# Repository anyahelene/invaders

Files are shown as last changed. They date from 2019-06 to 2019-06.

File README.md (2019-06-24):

# invaders
##### A hand-held retro console based on the ATmega328P chip
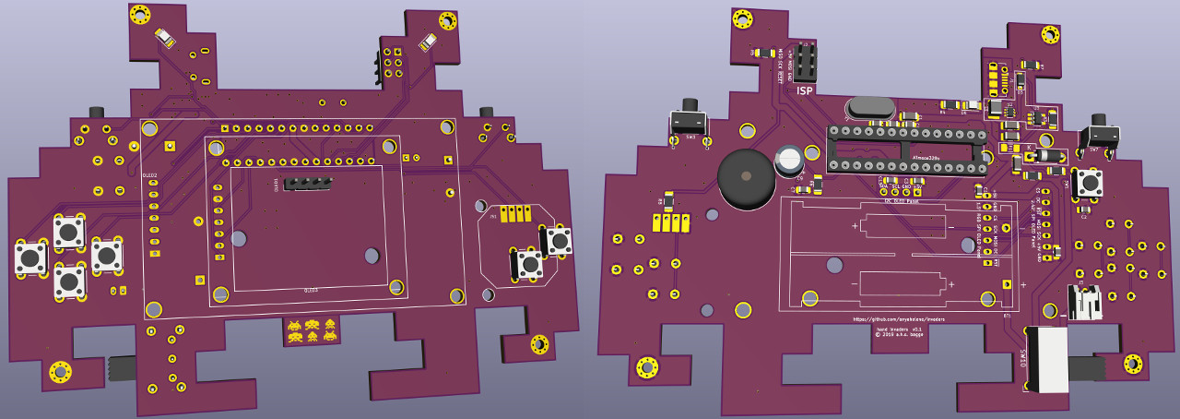
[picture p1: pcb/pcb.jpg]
3D model


## Features
* [ATmega328P](https://www.microchip.com/wwwproducts/en/ATMEGA328P) as the CPU, with
   * 16 MHz clock
   * 32 KiB flash memory for programs
   * 2 KiB static ram
   * 1 KiB EEPROM
* Choice of one of three OLED displays:
   * 2.42" monochrome 128x64 OLED with SPI interface, e.g., [this one from DIYMORE](https://www.diymore.cc/collections/display-module/products/2-42-inch-12864-oled-display-module-iic-i2c-spi-serial-for-arduino-c51-stm32-green-white-blue-yellow)
   * 1.5" color 128x128 OLED with SPI interface, e.g., [this one from Waveshare](https://www.waveshare.com/1.5inch-RGB-OLED-Module.htm)
   * 1.3" monochrome 128x64 OLED with I2C interface, found as infinite clones such as [this one from Luxorparts](https://www.kjell.com/no/produkter/elektro-og-verktoy/elektronikk/optokomponenter/led-lcd-skjermer/luxorparts-grafisk-oled-skjerm-128-x-64-piksler-1-3--p87946)
   * The board has pin headers and mounting holes for these three displays, but other display sizes might fit, and different pinouts might be accommodated by wires
   * The above displays are available from Ebay ($2.50 for a small display, up to ~$18 for large/color), and similar displays can be found at [Adafruit](https://adafruit.com/), [Sparkfun](https://sparkfun.com/) or your local electronics store
* Four directional buttons on the left-hand side
* [Thumbstick (PSP1000 replacement)](https://www.adafruit.com/product/444) *or* two buttons on the right-hand side
* Two trigger buttons on the top edge
* Reset button on the bottom side
* Space for 2xAAA batteries + also a JST-PH battery connector (as seen on the micro:bit)
* Micro USB power connector
* 6 pin AVR ICSP header for programming
* Space for a tiny speaker/buzzer
* Power led + two controllable leds
* Four M2 mounting holes

## (Soft|Firm)ware
* TBD

## Circuit board
* [KiCad](http://www.kicad-pcb.org/) files for the board can be found in the [pcb/](pcb/) subdirectory.
* You also need the symbols and footprints from https://github.com/anyahelene/a-symbols
* Alternatively, the board can be manufactured directly from the Gerber files in [pcb/fab/](pcb/fab/).
* An [interactive BOM](https://htmlpreview.github.io/?https://github.com/anyahelene/invaders/blob/master/pcb/bom/ibom.html) is available in [pcb/bom/](pcb/bom/)

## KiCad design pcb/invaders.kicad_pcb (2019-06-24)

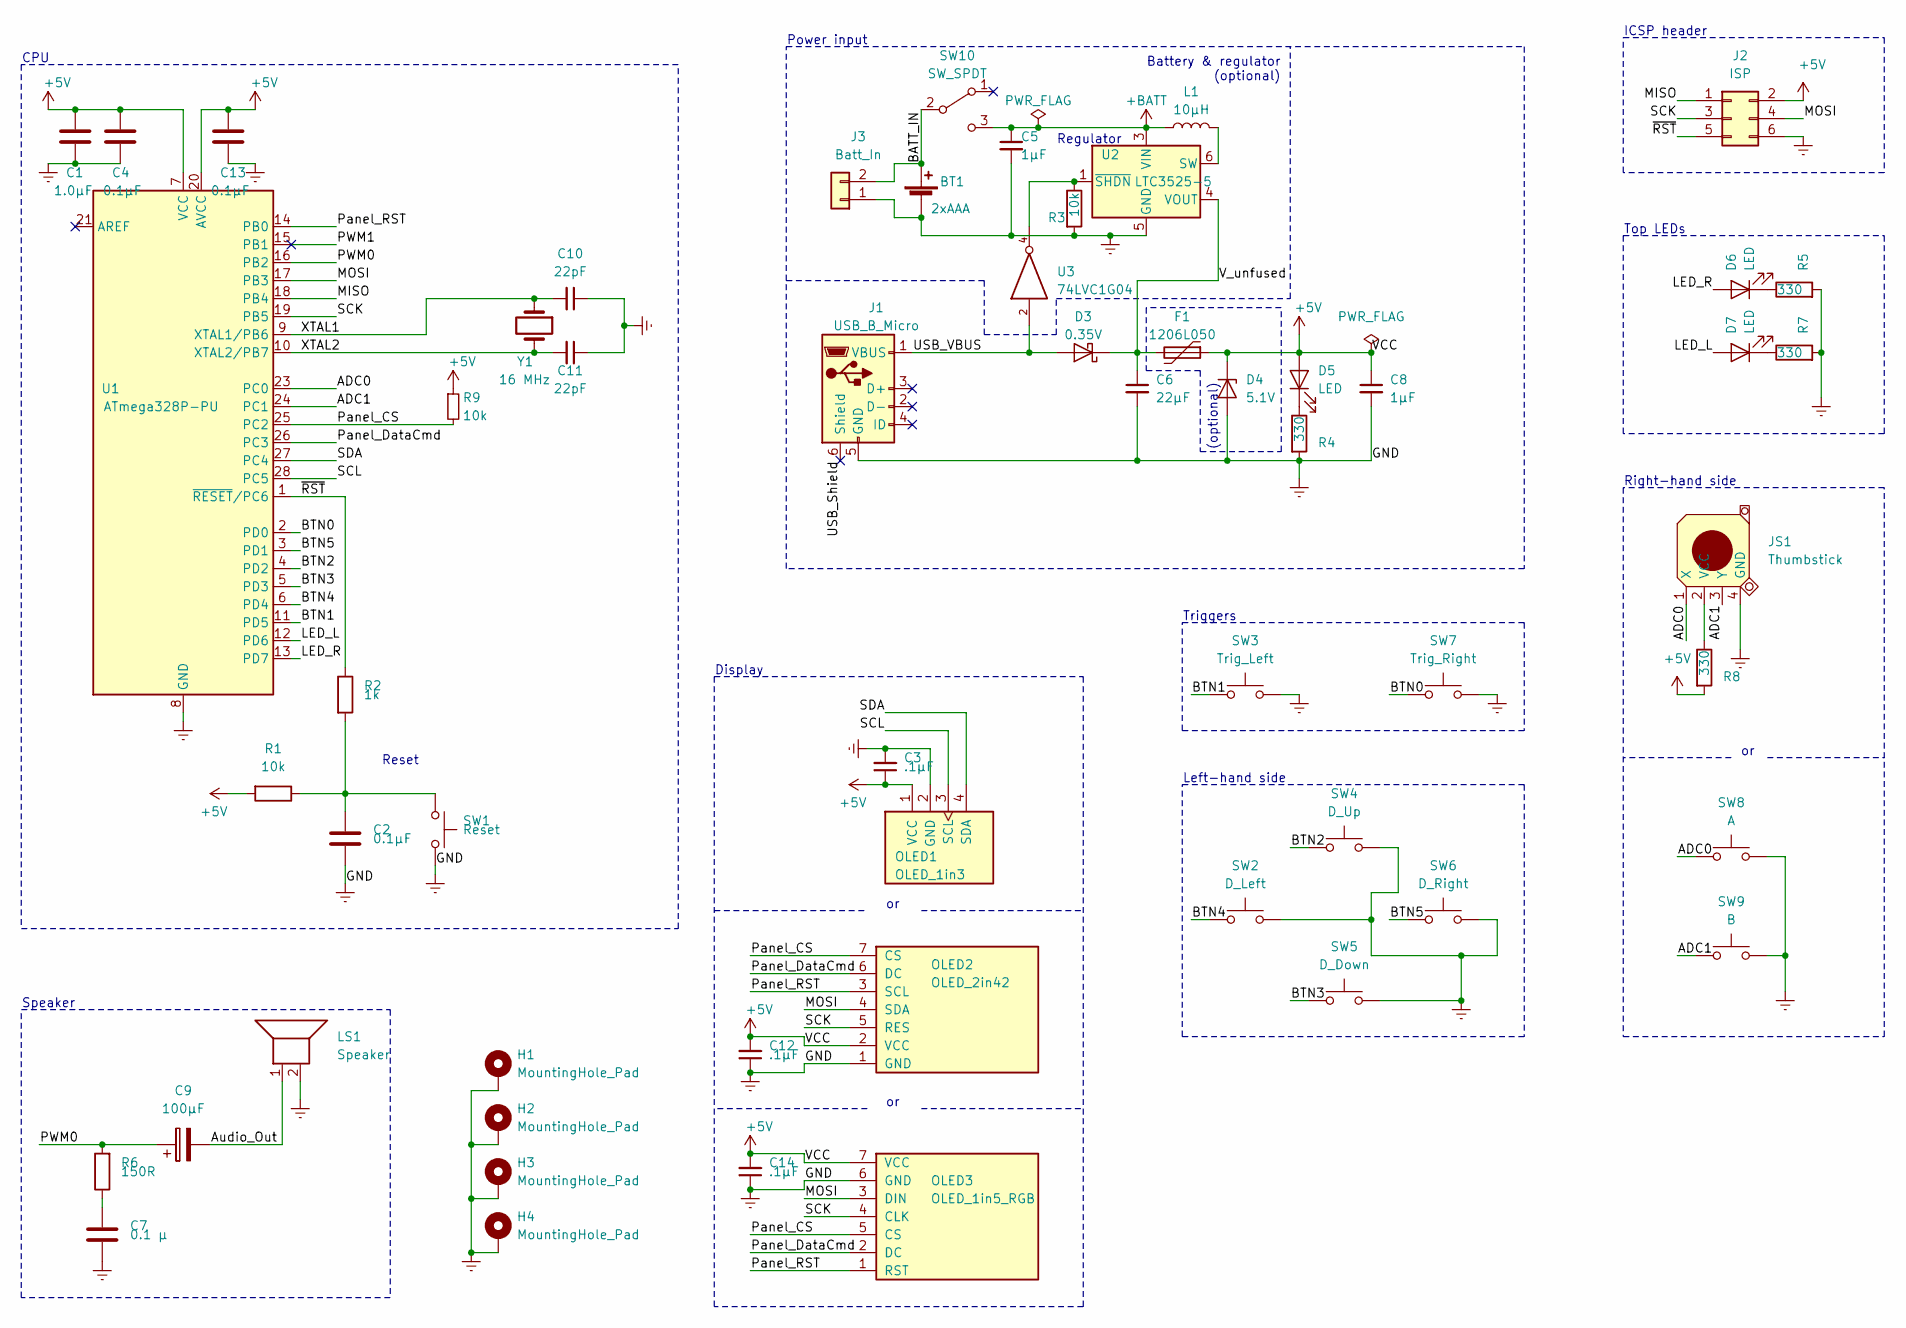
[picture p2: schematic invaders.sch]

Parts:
BT1: 2xAAA; BatteryHolder_Keystone_2468_2xAAA; Part Keystone 2468
C1: 1.0µF; C_1206_3216Metric_Pad1.42x1.75mm_HandSolder
C2, C4, C13: 0.1µF; C_0805_2012Metric_Pad1.15x1.40mm_HandSolder
C3, C12, C14: .1µF; C_0805_2012Metric_Pad1.15x1.40mm_HandSolder
C5, C8: 1µF; C_1206_3216Metric_Pad1.42x1.75mm_HandSolder
C6: 22µF; C_1206_3216Metric_Pad1.42x1.75mm_HandSolder; Part Taiyo LMK316ABJ226ML-T
C7: 0.1 µ; C_0805_2012Metric_Pad1.15x1.40mm_HandSolder
C9: 100µF; CP_Radial_D6.3mm_P2.50mm
C10, C11: 22pF; C_0805_2012Metric_Pad1.15x1.40mm_HandSolder
D3: 0.35V; D_SOD-123F; Part Rohm RSX101MM-30TR
D4: 5.1V; D_DO-41_SOD81_P7.62mm_Horizontal; Part RND 1N4733A
D5, D6, D7: LED; LED_1206_3216Metric_Pad1.42x1.75mm_HandSolder
F1: 1206L050; Fuse_1206_3216Metric_Pad1.42x1.75mm_HandSolder
H1, H2, H3, H4: MountingHole_Pad; MountingHole_2.2mm_M2_Pad_Via
J1: USB_B_Micro; USB_Micro-B_Molex-105017-0001; Part Molex 105017
J2: ISP; PinHeader_2x03_P2.54mm_Vertical
J3: Batt_In; JST_PH_S2B-PH-K_1x02_P2.00mm_Horizontal
JS1: Thumbstick; psp_thumbstick; Part PSP1000 thumbstick
L1: 10µH; L_1210_3225Metric_Pad1.42x2.65mm_HandSolder; Part Murata DFE322512C 1277A
LS1: Speaker; Buzzer_12x9.5RM7.6
OLED1: OLED_1in3; OLED_1in3_i2c
OLED2: OLED_2in42; OLED_2in42_spi_i2c
OLED3: OLED_1in5_RGB; OLED_1in5_spi_rgb
R1, R3, R9: 10k; R_1206_3216Metric_Pad1.42x1.75mm_HandSolder
R2: 1k; R_1206_3216Metric_Pad1.42x1.75mm_HandSolder
R4, R5, R7, R8: 330; R_1206_3216Metric_Pad1.42x1.75mm_HandSolder
R6: 150R; R_1206_3216Metric_Pad1.42x1.75mm_HandSolder
SW1: Reset; SW_PUSH_6mm; Part 6x6mm tactile, e.g. ALPS SKHHAMA010
SW2: D_Left; SW_PUSH_6mm; Part 6x6mm tactile, e.g. ALPS SKHHAMA010
SW3: Trig_Left; SW_Tactile_SPST_Angled_PTS645Vx58-2LFS; Part 6mm angled tactile, e.g. C&K PTS645VM58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
SW4: D_Up; SW_PUSH_6mm; Part 6x6mm tactile, e.g. ALPS SKHHAMA010
SW5: D_Down; SW_PUSH_6mm; Part 6x6mm tactile, e.g. ALPS SKHHAMA010
SW6: D_Right; SW_PUSH_6mm; Part 6x6mm tactile, e.g. ALPS SKHHAMA010
SW7: Trig_Right; SW_Tactile_SPST_Angled_PTS645Vx58-2LFS; Part 6mm angled tactile, e.g. C&K PTS645VM58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
SW8: A; SW_PUSH_6mm; Part 6x6mm tactile, e.g. ALPS SKHHAMA010
SW9: B; SW_PUSH_6mm; Part 6x6mm tactile, e.g. ALPS SKHHAMA010
SW10: SW_SPDT; SW_E-Switch_EG1224_SPDT_Angled
U1: ATmega328P-PU; DIP-28_W7.62mm_Socket
U2: LTC3525-5; SOT-363_SC-70-6
U3: 74LVC1G04; SOT-23-5_HandSoldering
Y1: 16 MHz; Crystal_HC49-4H_Vertical

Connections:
+5V: C1.1, C3.1, C4.1, C8.1, C12.2, C13.1, C14.2, D4.1 (K), D5.2 (A), F1.1, J2.2, OLED1.1 (VCC), OLED2.2 (VCC), OLED3.7 (VCC), R1.2, R8.2, R9.1, U1.7 (VCC), U1.20 (AVCC), U3.5 (VCC)
+BATT: C5.1, L1.1, SW10.3 (C), U2.3 (VIN)
/ADC0: JS1.1 (X), SW8.1, U1.23 (PC0)
/ADC1: JS1.3 (Y), SW9.1, U1.24 (PC1)
/Audio_Out: C9.2, LS1.1
/BATT_IN: BT1.1 (+), J3.2, SW10.2 (B)
/BTN0: SW7.1, U1.2 (PD0)
/BTN1: SW3.1, U1.11 (PD5)
/BTN2: SW4.1, U1.4 (PD2)
/BTN3: SW5.1, U1.5 (PD3)
/BTN4: SW2.1, U1.6 (PD4)
/BTN5: SW6.1, U1.3 (PD1)
/LED_L: D7.2 (A), U1.12 (PD6)
/LED_R: D6.2 (A), U1.13 (PD7)
/MISO: J2.1, U1.18 (PB4)
/MOSI: J2.4, OLED2.4 (SDA), OLED3.3 (DIN), U1.17 (PB3)
/PWM0: C9.1, R6.2, U1.16 (PB2)
/Panel_CS: OLED2.7 (CS), OLED3.5 (CS), R9.2, U1.25 (PC2)
/Panel_DataCmd: OLED2.6 (DC), OLED3.2 (DC), U1.26 (PC3)
/Panel_RST: OLED2.3 (SCL), OLED3.1 (RST), U1.14 (PB0)
/SCK: J2.3, OLED2.5 (RES), OLED3.4 (CLK), U1.19 (PB5)
/SCL: OLED1.3 (SCL), U1.28 (PC5)
/SDA: OLED1.4 (SDA), U1.27 (PC4)
/USB_Shield: J1.6 (Shield)
/USB_VBUS: D3.2 (A), J1.1 (VBUS), U3.2
/V_unfused: C6.1, D3.1 (K), F1.2, U2.4 (VOUT)
/XTAL1: C10.2, U1.9 (XTAL1/PB6), Y1.1
/XTAL2: C11.2, U1.10 (XTAL2/PB7), Y1.2
/~RST: J2.5, R2.1, U1.1 (~RESET~/PC6)
Earth: BT1.2 (-), C1.2, C2.1, C3.2, C4.2, C5.2, C6.2, C7.1, C8.2, C10.1, C11.1, C12.1, C13.2, C14.1, D4.2 (A), H1.1, H2.1, H3.1, H4.1, J1.5 (GND), J2.6, J3.1, JS1.4 (GND), LS1.2, OLED1.2 (GND), OLED2.1 (GND), OLED3.6 (GND), R3.2, R4.2, R5.2, R7.2, SW1.2, SW2.2, SW3.2, SW4.2, SW5.2, SW6.2, SW7.2, SW8.2, SW9.2, U1.8 (GND), U1.22 (GND), U2.2 (GND), U2.5 (GND), U3.3 (GND)
unnamed: C2.2, R1.1, R2.2, SW1.1
unnamed: C7.2, R6.1
unnamed: D5.1 (K), R4.1
unnamed: D6.1 (K), R5.1
unnamed: D7.1 (K), R7.1
unnamed: JS1.2 (VCC), R8.1
unnamed: L1.2, U2.6 (SW)
unnamed: R3.1, U2.1 (~SHDN), U3.4

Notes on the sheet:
Regulator
Right-hand side
Triggers
Left-hand side
Display
Reset
CPU
Top LEDs
ICSP header
(optional)
Battery & regulator (optional)
Power input
Speaker

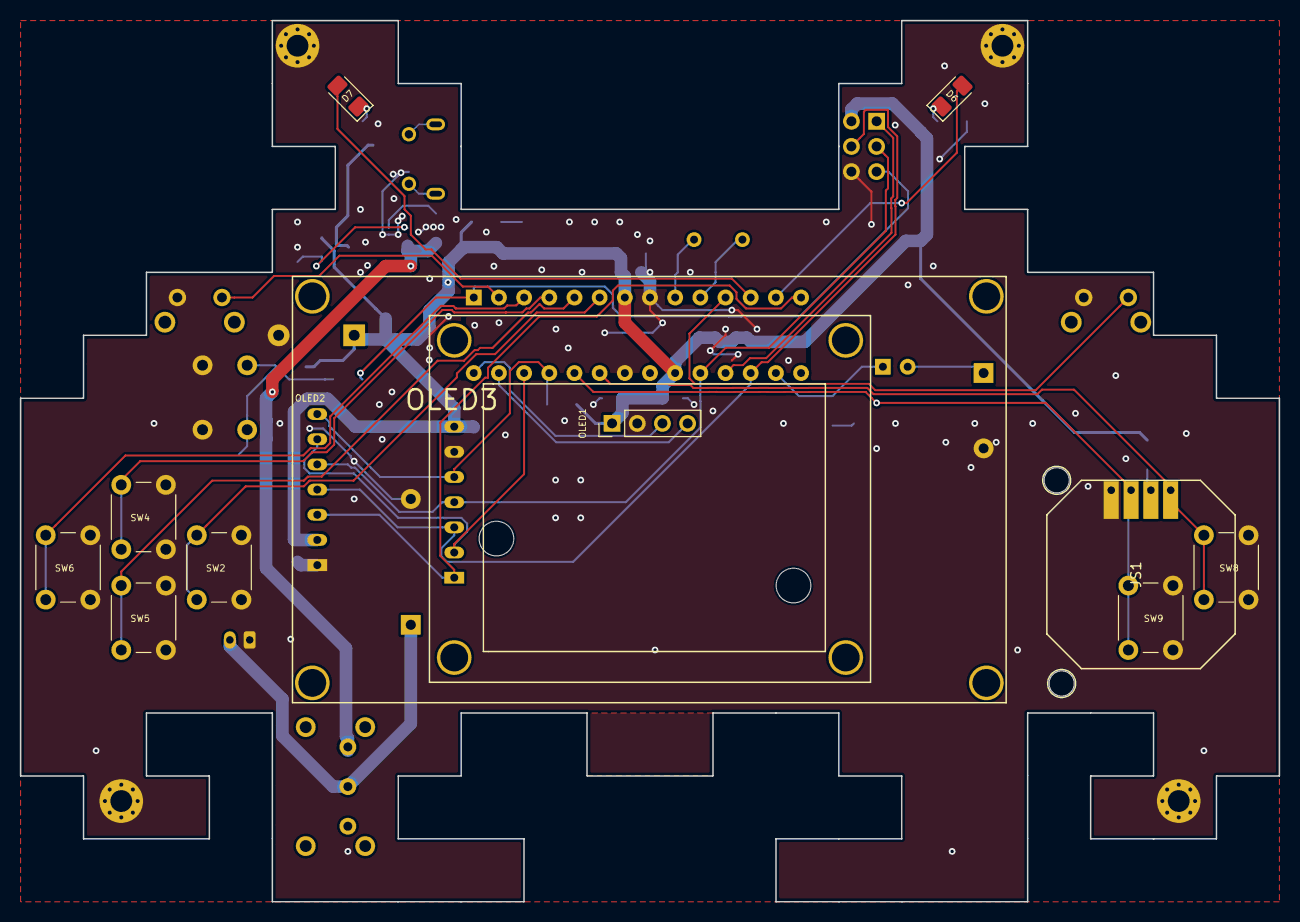
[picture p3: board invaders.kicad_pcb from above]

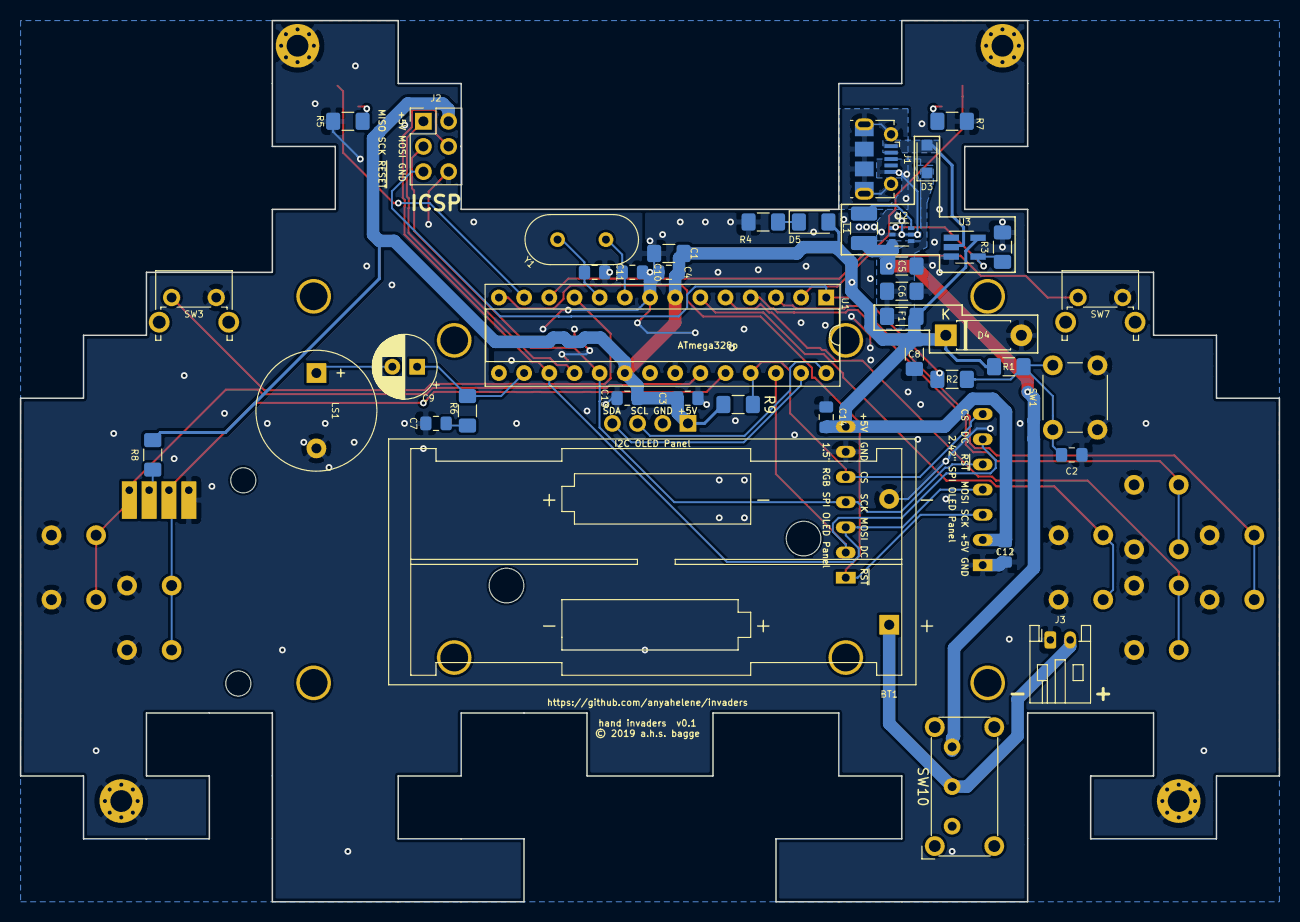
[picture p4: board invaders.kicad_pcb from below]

Board: 2 copper layers, 127.0 x 88.9 mm, 57 parts (41 on the bottom side), 37 nets.

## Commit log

2019-06-24 library fixes
    [invaders.kicad_pcb, invaders.sch]
2019-06-24 cleanup; add pullup to Panel_CS
    [invaders-B.Cu.gbr, invaders-B.Mask.gbr, invaders-B_Cu.gbr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]

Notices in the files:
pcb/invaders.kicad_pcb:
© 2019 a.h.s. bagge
